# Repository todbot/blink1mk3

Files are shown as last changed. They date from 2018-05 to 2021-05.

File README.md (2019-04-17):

# blink(1) mk3 -- USB RGB LED notification light

This repo lives at https://github.com/todbot/blink1mk3

blink(1) mk3 is a blink(1) USB device: https://blink1.thingm.com

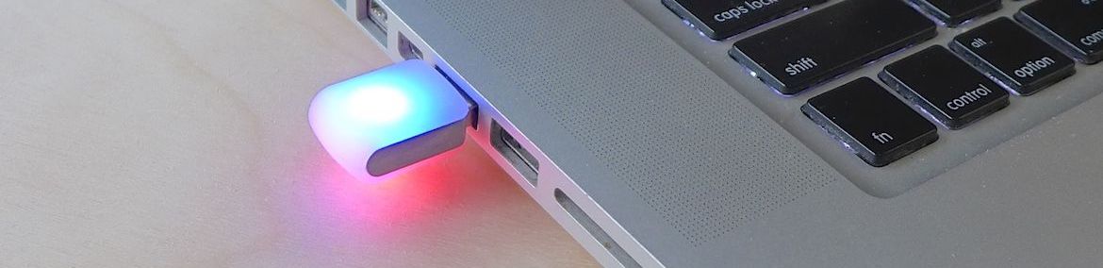
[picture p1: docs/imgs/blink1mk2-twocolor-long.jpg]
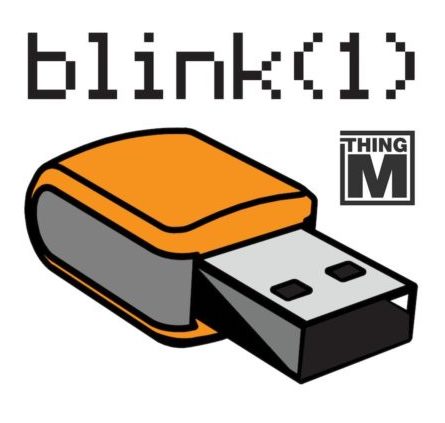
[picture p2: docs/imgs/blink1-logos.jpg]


"[blink(1) mk3](https://blink1.thingm.com/) is an update to blink(1).
blink(1) is a super status light:
it packs three dimensions of information
(color, brightness and pattern) into a single tiny package that fits into
any USB port on nearly every device. It makes it incredibly easy to connect
any data source in the cloud or on your computer to a full-color RGB LED so
you can know what's happening without checking any windows, going to any
websites or typing any commands." - Get a blink(1) at https://buy.thingm.com/

More technically, blink(1) is a Smart LED controller with built-in USB firmware. blink(1) has a huge range of support from the Linux kernel to Node.js.

This repo contains:

- firmware -- blink(1) firmware for blink1mk3 (on DEFM32HG309F64, same as Tomu)
- bootloader -- DFU firmware for blink(1), based on tomu-bootloader
- schematic -- schematic diagrams of blink(1) mk3

The official repositories for blink(1) software are:

| repository | description |
| --- | --- |
| [Blink1Control2](https://github.com/todbot/Blink1Control2) | Graphical app for Mac / Windows / Linux |
| [blink1-tool](https://github.com/todbot/blink1-tool) | Command-line tools & C-library for all platforms |
| [blink1-java](https://github.com/todbot/blink1-java) | Java and Processing library |
| [blink1-python](https://github.com/todbot/blink1-python) | Python library |
| [node-blink1](https://github.com/sandeepmistry/node-blink1) | Node.js library |
| [blink1](https://github.com/todbot/blink1) | Hardware/firmware design for mk1/mk2, misc docs & notes
| [blink1mk3](https://github.com/todbot/blink1mk3) | Hardware/firmware design for mk3

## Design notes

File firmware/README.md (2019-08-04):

# blink1mk3 firmware

## What is this:

This is firmware for the blink(1) mk3 USB RGB LED device.
It borrows heavily from the [Tomu](http://tomu.im) project.
This directory started as a fork of the
[tomu-samples](https://github.com/im-tomu/tomu-samples) repository.

## How to use:

1. To compile these, you'll need a cross-compiling toolchain to arm-none-eabi.

  - Debian/Ubuntu/... : `sudo apt-get install gcc-arm-none-eabi`
  - Fedora : `sudo yum install arm-none-eabi-gcc-cs arm-none-eabi-newlib`
  - Arch : `sudo pacman -S arm-none-eabi-gcc arm-none-eabi-newlib`
  - Other Linux : check your package manager, or
  - Anything else (Windows, OSX, Linux) : [https://developer.arm.com/open-source/gnu-toolchain/gnu-rm ](https://developer.arm.com/open-source/gnu-toolchain/gnu-rm )

  If the cross compiling toolchain is in your PATH then the Makefile will
  auto-detect it; else (or to override it) specify it using the environment
  variable "CROSS_COMPILE".
  There might be additional dependencies, depending on which specific project
  you're using, and the instructions for compilation are included in each
  project's README.md

2. Run `make deps .` to patch the linker with support for the blink(1) and Tomu
    and clone the [Gecko SDK](https://github.com/SiliconLabs/Gecko_SDK) locally

3. Now you can build the firmware.

4. The production firmware is located in `firmware-v30x`.

## Flashing:

The easiest way to upload a new firmware is to trigger the USB DFU bootloader
and use `dfu-util` to upload the new firmware.  For an example of how to do this,
see the "program-dfu" Makefile target in `firmware-v30x` or the "fw-updates" directory.

You can also solder wires to the programming test pads:
"5V" (+5VDC), "G" (gnd), "D" (SWD), "C" (SWC) pins
then use any JTAG/SWD programmer to upload new code.

## Testing:

In Windows, install the app "TDD.exe"
(https://www.thesycon.de/eng/usb_descriptordumper.shtml)
It is very good at detecting subtle errors in USB configuration that MacOS & Linux
point out.

On Mac OS X, install "USB Prober"

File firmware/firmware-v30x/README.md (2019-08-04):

# blink(1) mk3 - firmware-v30x

This is the standard firmware for blink(1) mk3 devices.

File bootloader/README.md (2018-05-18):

# blink(1) mk3 bootloader

This bootloader is equivalent to the Tomu bootloader with a few small changes:
- USB VID/PID different
- Bootloader can ONLY be triggered by either:
  - SWD & SWC pins shorted
  - RAM setting "TOBOOT_FORCE_ENTRY_MAGIC" (via `blink1-tool --gobootload`)

These changes are encapsulated in the files in this directory:
- `usb_desc.h` -- replaces normal `tomu-bootloader/toboot/usb_desc.h`
- `toboot-main-blink1.c` -- replaces normal `tomu-bootloader/toboot/main.c`

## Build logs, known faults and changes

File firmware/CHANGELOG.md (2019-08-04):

# blink(1) mk3 firmware changelog

List of official firmwares for blink(1) mk3:

- v302 -- 2018-2019 production firmware

- v303 -- 2Aug2019 - work-around for USB Suspend causing main thread(and pattern playing) to stop.

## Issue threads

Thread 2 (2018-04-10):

Add option to ensure physical security of bootloader

todbot, 2018-04-10:
As @carlynorama pointed out, blink(1) mk3's reprogrammability could pose security issues for certain users. To address this, create a new feature in the blink(1) API and firmware that disables USB-based triggering of the DFU bootloader.

The process would be:
- New USB command that "locks out" the USB triggering of the bootloader
- Bootloader will then only run when 'S' & 'D' solder pads are physically jumpered, meaning physical access to device, and the device removed from its enclosure
- To re-enable "unlocked" mode, factory firmware must be reloaded onto device

todbot, 2019-04-17:
done.

Closed 2019-04-17.

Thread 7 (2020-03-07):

Firmware Update not running

lucaobermaier, 2020-03-07:
Firmware Update is not running correctly:

Last login: Sat Mar  7 18:49:14 on ttys000
lucaobermaier@Lucas-MBP ~ % /Users/lucaobermaier/Downloads/blink1mk3-master/blink1mk3_fw_update/blink1mk3-update-macos.command ; exit;
------
Putting blink(1) into bootloader mode
Changing blink(1) mk3 to bootloader...
Use dfu-util to upload new firmare
Or replug device to go back to normal
blink1 response: 'GOBOOT'
blink(1) in bootloader mode
------
Waiting for bootloader USB reconnect...
c------
Programming new firmware
dyld: Library not loaded: /usr/local/opt/libusb/lib/libusb-1.0.0.dylib
  Referenced from: /Users/lucaobermaier/Downloads/blink1mk3-master/blink1mk3_fw_update/./tools/dfu-util
  Reason: image not found
/Users/lucaobermaier/Downloads/blink1mk3-master/blink1mk3_fw_update/blink1mk3-update-macos.command: line 14: 88017 Abort trap: 6           ./tools/dfu-util -v --device 27B8:01ED --download *dfu
------
Done!

todbot, 2020-03-07:
Hi,
Do you use Homebrew (https://brew.sh/)?  That error is because the `dfu-util` tool can't find the libusb library. (I tried to make static versions of that tool but clearly did not)

If you use Homebrew, you can do `brew install libusb` and try rerunning the update command.

If you don't use Homebrew, I'm looking into getting a statically-compiled version of `dfu-util`.

Thanks for being patient.

lucaobermaier, 2020-03-07:
Hey,

Thanks for the quick reply.
No I am not using home-brew.
I also get the error on the windows machine: " Could not open file *dfu for reading.“
Is that the same thing?
Best regards

Luca Obermaier
Event Technology Specialist

Obermaier Event Support
Nachtigallenweg 13
65719 Hofheim am Taunus
Phone: +49 (0) 6192/2069694
Mobile: +49 (0) 151/27003039
Fax: +49 (0) 3222/4284647
E-mail: mail@lucaobermaier.de
Website:: www.lucaobermaier.de

Die AGB finden Sie auf der oben genannten Webpräsenz.

Vertraulichkeitshinweis:
Diese Nachricht ist ausschließlich für die Personen bestimmt, an die sie adressiert ist. Sie kann vertrauliche und/oder nur für den/die Empfänger bestimmte Informationen enthalten. Sollten Sie nicht der bestimmungsgemäße Empfänger sein, kontaktieren Sie bitte den Absender und löschen Sie die Mitteilung. Jegliche unbefugte Verwendung der Informationen in dieser Nachricht ist untersagt.

Confidentiality Note:
This message is intended only for the use of the named recipient(s) and may contain confidential and/or privileged information. If you are not the intended recipient, please contact the sender and delete the message. Any unauthorized use of the information contained in this message is prohibited.

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

todbot, 2020-03-07:
Are you running the Windows .bat file from a CMD window or Powershell?  It is only for a CMD window.

Apologies these aren't scripts aren't tested much.  There's only been one official firmware update for blink(1) mk3 (some early units had v302, most all current ones have v303)   You can find your blink(1)'s version by doing `blink1-tool --version`.

It's likely you do not need to update the firmware on your blink(1) anyway.

I have updated https://github.com/todbot/blink1mk3/releases with "blink1mk3_fw_update_fw303-2Aug2019b.zip", containing an updated `dfu-util` for Mac. If you still want to give it a try, I think that one will work.

lucaobermaier, 2020-03-07:
I was using CMD not powershelgl.

I have some 302 early units and problems with the blink1 control center. My hope was that the firmware update will fix those crashes.
Just downloaded the new release.

Last login: Sat Mar  7 20:00:35 on ttys000
/Users/lucaobermaier/Downloads/blink1mk3_fw_update/blink1mk3-update-macos.command ; exit;
lucaobermaier@Lucas-MBP ~ % /Users/lucaobermaier/Downloads/blink1mk3_fw_update/blink1mk3-update-macos.command ; exit;
------
Putting blink(1) into bootloader mode
Changing blink(1) mk3 to bootloader...
Use dfu-util to upload new firmare
Or replug device to go back to normal
blink1 response: 'GOBOOT'
blink(1) in bootloader mode
------
Waiting for bootloader USB reconnect...
------
Programming new firmware
dfu-util 0.9

Copyright 2005-2009 Weston Schmidt, Harald Welte and OpenMoko Inc.
Copyright 2010-2016 Tormod Volden and Stefan Schmidt
This program is Free Software and has ABSOLUTELY NO WARRANTY
Please report bugs to http://sourceforge.net/p/dfu-util/tickets/

DFU suffix version 100
Opening DFU capable USB device...
ID 27b8:01ee
Run-time device DFU version 0101
Claiming USB DFU Interface...
Setting Alternate Setting #0 ...
dfu-util: Cannot set alternate interface
------
Done!

[Prozess beendet]

Stil on 302.

Best regards

Luca Obermaier
Event Technology Specialist

Obermaier Event Support
Nachtigallenweg 13
65719 Hofheim am Taunus
Phone: +49 (0) 6192/2069694
Mobile: +49 (0) 151/27003039
Fax: +49 (0) 3222/4284647
E-mail: mail@lucaobermaier.de
Website:: www.lucaobermaier.de

Die AGB finden Sie auf der oben genannten Webpräsenz.

Vertraulichkeitshinweis:
Diese Nachricht ist ausschließlich für die Personen bestimmt, an die sie adressiert ist. Sie kann vertrauliche und/oder nur für den/die Empfänger bestimmte Informationen enthalten. Sollten Sie nicht der bestimmungsgemäße Empfänger sein, kontaktieren Sie bitte den Absender und löschen Sie die Mitteilung. Jegliche unbefugte Verwendung der Informationen in dieser Nachricht ist untersagt.

Confidentiality Note:
This message is intended only for the use of the named recipient(s) and may contain confidential and/or privileged information. If you are not the intended recipient, please contact the sender and delete the message. Any unauthorized use of the information contained in this message is prohibited.

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

todbot, 2020-03-07:
Hi,
This is probably a Mac Catalina issue.  Many tools like these have had issues since Catalina.  .I'm also seeing this now and dfu-util worked before I upgraded.

Please describe in more detail these crashes you've been having. If Blink1Control2 is crashing on you, updating the firmware on the blink(1) will not help.   Please open up an issue describing the what you're seeing at: https://github.com/todbot/blink1control2/issues

The firmware update only addresses use cases where you're using the `blink1-tool --play` internal pattern player, which Blink1Control2 does not use. I'll continue investigating what is wrong with Mac dfu-util but I think we should address the crashes first.

Thanks

lucaobermaier, 2020-03-07:
I tried your install with windows now.
There it work perfectly.
Thats solved 😉

Luca Obermaier
Event Technology Specialist

Obermaier Event Support
Nachtigallenweg 13
65719 Hofheim am Taunus
Phone: +49 (0) 6192/2069694
Mobile: +49 (0) 151/27003039
Fax: +49 (0) 3222/4284647
E-mail: mail@lucaobermaier.de
Website:: www.lucaobermaier.de

Die AGB finden Sie auf der oben genannten Webpräsenz.

Vertraulichkeitshinweis:
Diese Nachricht ist ausschließlich für die Personen bestimmt, an die sie adressiert ist. Sie kann vertrauliche und/oder nur für den/die Empfänger bestimmte Informationen enthalten. Sollten Sie nicht der bestimmungsgemäße Empfänger sein, kontaktieren Sie bitte den Absender und löschen Sie die Mitteilung. Jegliche unbefugte Verwendung der Informationen in dieser Nachricht ist untersagt.

Confidentiality Note:
This message is intended only for the use of the named recipient(s) and may contain confidential and/or privileged information. If you are not the intended recipient, please contact the sender and delete the message. Any unauthorized use of the information contained in this message is prohibited.

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

todbot, 2020-03-07:
That's good.  I've also found the issue with `dfu-util` on MacOS and updated the zip yet again.

So I'll close this issue. But if you have crashes in Blink1Control2, please open up an issue there.

Thanks for being a customer and thanks for pointing out this problem with the update script.

lucaobermaier, 2020-03-07:
I will do. Blink1control is a different thing 😉
Thanks for taking care so fast. 👏🏽

Best regards

Von meinem iPhone gesendet

Luca Obermaier
Fachkraft für Veranstaltungstechnik

Obermaier Event Support
Nachtigallenweg 13
65719 Hofheim am Taunus
Phone: +49 (0) 6192/2069694
Mobile: +49 (0) 151/27003039
Fax: +49 (0) 3222/4284647
E-mail: mail@lucaobermaier.de
Website:: www.lucaobermaier.de

Die AGB finden Sie auf der oben genannten Webpräsenz.

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

Closed 2020-03-07.

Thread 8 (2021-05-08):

blink1-tool --setstartup doesn't quite work

ChrMa, 2021-05-08:
Hi,

I noticed, that when I use `--setstartup` to keep the blink1mk3 from running it's sequence when power is applied (mode 2), it won't let me start playing the programmed sequence using `blink1-tool --play` either. It seems to me that there is a bug in firmware/firmware-v30x/main.c, line 708, where `doStartup` is set every time after the first second of runtime.

Another problem I encountered is, that when I program the blink1mk3 to play just part of it's sequence or just a few repetitions on power up, e.g. using `blink1-tool --setstartup 0,0,5,10`, it nevertheless plays the full sequence without ever stopping.
```
$ blink1-tool --setstartup 0,0,5,10
set startup params: bootmode: 0, play start/end/count: 0/5/10
$ /bin/blink1-tool --getstartup
get startup params: bootmode: 0, play start/end/count: 0/5/10
```
When connecting it to a power bank afterwards, the full sequence plays. When using bootmode 1, it even says so when reading back the playstate:
```
$ blink1-tool --setstartup 1,0,5,10
set startup params: bootmode: 1, play start/end/count: 0/5/10
$ blink1-tool --getstartup
get startup params: bootmode: 1, play start/end/count: 0/5/10
$ # unplug an reinsert blink1 device
$ blink1-tool --getstartup
get startup params: bootmode: 1, play start/end/count: 0/5/10
$ blink1-tool --playstate
playstate: playing:1 start-end:0-31 count:0 pos:6
```
I wasn't able to spot any suspicious line of code, that would explain this phenomenon however.

ChrMa, 2021-05-08:
Sorry, forgot to add version information.
```
$ blink1-tool --version
blink1-tool version: v2.1.0-linux-x86_64, fw version: 303
$ blink1-tool --fwversion
id:0 - firmware:303 serialnum:********
```

todbot, 2021-05-08:
Hi @ChrMa,

For the first issue (`--play` not working as expected), how are you invoking it?  You need to say:
```
blink1-tool --play 1
```
to start the pattern playing and
```
blink1-tool --play 0
```
to stop.  Or `blink1-tool --stop`.  (This is support upstream callers of `blink1-tool` that expects to be able to pass an argument for play/stop).  Apologies that isn't documented well.

As to the second issue you mention about the startup parameters not being heeded, I am looking into that now.

ChrMa, 2021-05-08:
To recreate the first issue, I start off with resetting the device to defaults:
```
$ blink1-tool --setstartup 0,0,31,0
set startup params: bootmode: 0, play start/end/count: 0/31/0
```
Now i disconnect and reconnect the device. It briefly flashes white, then stays off.
```
$ blink1-tool --getstartup
get startup params: bootmode: 0, play start/end/count: 0/31/0
$ blink1-tool --playstate
playstate: playing:0 start-end:0-31 count:0 pos:0
```
Now I switch to mode 1:
```
$ blink1-tool --setstartup 1,0,31,0
set startup params: bootmode: 1, play start/end/count: 0/31/0
```
The device immediately plays the preprogrammed color sequence. I disconnect and reconnect it again and shortly after the white flash it starts playing the pattern. Now I try to stop it:
```
$ blink1-tool --play 0
stopping color pattern from pos 0-0 (0 times)
```
However it doesn't stop, it just jumps back to the beginning of the programmed pattern and continues playing it from there. Trying to stop it multiple times also doen't help, it always just jumps back to the beginning of the sequence.

Now lets switch to mode 2:
```
$ blink1-tool --setstartup 2,0,31,0
set startup params: bootmode: 2, play start/end/count: 0/31/0
```
Immediately, the device stops playing the pattern. I disconnect and reconnect it to the computer. It briefly flashes white and then stays dark. Now I try to start the pattern again:
```
$ blink1-tool --play 1
playing color pattern from pos 0-0 (0 times)
```
For a split second one of the LEDs start ramping up the red light, then the sequence stops and the red light is on continuously.
If I call `blink1-tool --play 1` again, nothing visible happens, one LED stays  red, the other one stays dark.
By the way: ramping up one LED in red is the first step of the preprogrammed pattern sequence:
```
$ blink1-tool --getpattline 0
reading rgb at pos  0: r,g,b = 0xff,0x00,0x00 (1) ms:500
```
Hope that helps.

todbot, 2021-05-08:
Thanks for the detailed description. It's very helpful. I am investigating now. I will admit the built-in color pattern code is not as well exercised as it used by many fewer people. It should still work though.

todbot, 2021-05-08:
Hi, I just published an attempted fix for the issue you describe. You can install it using a Chrome-based browser as described here: https://github.com/todbot/blink1mk3/releases/tag/firmware-v304

Let me know if it works for you. I'm still testing but I wanted to provide a testable solution for you as quickly as possible.

Thank you for submitting this issue! I've been wanting to revisit the blink(1) mk3 firmware.

ChrMa, 2021-05-09:
Thanks for the fix. The issues I described in my last message are completely resolved. I can now start and stop the playing of patterns as expected, no matter what bootmode the blink1 device started with. Also changing the bootmode with `--setstartup` no longer has any immediate effect on the playstatus. For my use case, this is good enough.

However the problem where the play start/end/count parts of the '--setstartup' parameters are ignored still persists and I haven't got the slightest clue as to what is causing this. For context: my device still has the original blink pattern programmed in, so
```
$ blink1-tool --play 1,3,5,2
playing color pattern from pos 3-5 (2 times)
```
ramps up both leds in green, one after the other, and then ramps both down to black simultaneously. After two cycles, it stops playing.
However when I do
```
$ blink1-tool --setstartup 1,3,5,2
set startup params: bootmode: 1, play start/end/count: 3/5/2
```
And then disconnect and reconnect the device, it starts playing the whole programmed sequence forever
```
$ blink1-tool --playstate
playstate: playing:1 start-end:0-31 count:0 pos:11
$ blink1-tool --getstartup
get startup params: bootmode: 1, play start/end/count: 3/5/2
```

ChrMa, 2021-05-09:
I think I just found the problem: The gcc compiler is just too intelligent for its own good.
In firmware/firmware-v30x/main.c, lines 868-879, you first copy the content of userFlash into userData and then copy the play start/end/count values from userData to the individual variables. At this point gcc seems to understand, that userData must contain the same as userFlash and that userFlash is constant and has to contain the values specified in lines 243-250, so it already knows what goes into the playstart, playend and playcount variables and doesn't bother to load it from either userData or userFlash.
So the line
```
playend   = userData.startup_params.playend;
```
becomes
```
movs    r2, #32
ldr     r3, [pc, #736]
strb    r2, [r3, #0]
```
My suggestion would be to remove the `const` qualifier from userFlash in line 240, which results in the above line to become
```
ldr     r7, [pc, #748]
ldrb    r2, [r7, #2]
ldr     r3, [pc, #740]
strb    r2, [r3, #0]
```
Unfortunately, since I don't have any debugger or even a means to recover from flashing broken software, I have not tested this change on real hardware.

todbot, 2021-05-09:
Hi!  Thanks again for the detailed look into this issue.  I've uploaded an updated firmware DFU for you to try on the Releases page called `blink1mk3-v304a-20210509.dfu`.  Please let me know if it solves the `setplaystate` issue for you. It does for me, but if you look at the change, I'm sure you'll be thinking "WTF?".

With these chips and its attendant SDK, there's a few different issues when dealing with flash memory for data storage. The most noticeable is that variables must be 32-bit aligned. This might actually be what's happening as the code works as intended when DEBUG is enabled (which adds a few buffers for the UART). My change adds a 100ms delay. It's a hack but might also be addressing the vague memory I have of the older EFM32 SDK I'm using not properly on flash reads.

ChrMa, 2021-05-09:
Thanks for the new firmware. I tested it and it worked flawlessly.

 I'm not sure I agree, that the extra 100ms delay made the difference. I think it's more likely the fact, that there is now a function call after `userDataLoad()`, which forces gcc to consider the data in userData to be possibly changed. You might want to compare the debug information in blink1mk3.dump before and after the fix for details.

Then again the firmware works now as expected, so I am satisfied. Thanks again for the support.

mhalano, 2022-07-23:
@ChrMa Can this issue be closed for good?

@todbot There is a reason why not release the 304 firmware to public use?

todbot, 2022-07-23:
Hi @mhalano,

Thanks! I had forgotten that v304 was labeled as pre-release and not normal release.
Just changed that now and will close this comment.

And thanks @ChrMa for raising this issue and testing!

mhalano, 2022-07-23:
@todbot Just a remaining question: what is the correct file? I checked and they have different checksums.
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

todbot, 2022-07-23:
Thanks. I've eliminated the older one.  (Everything was was a bit hectic a year ago)

Closed 2022-07-23.

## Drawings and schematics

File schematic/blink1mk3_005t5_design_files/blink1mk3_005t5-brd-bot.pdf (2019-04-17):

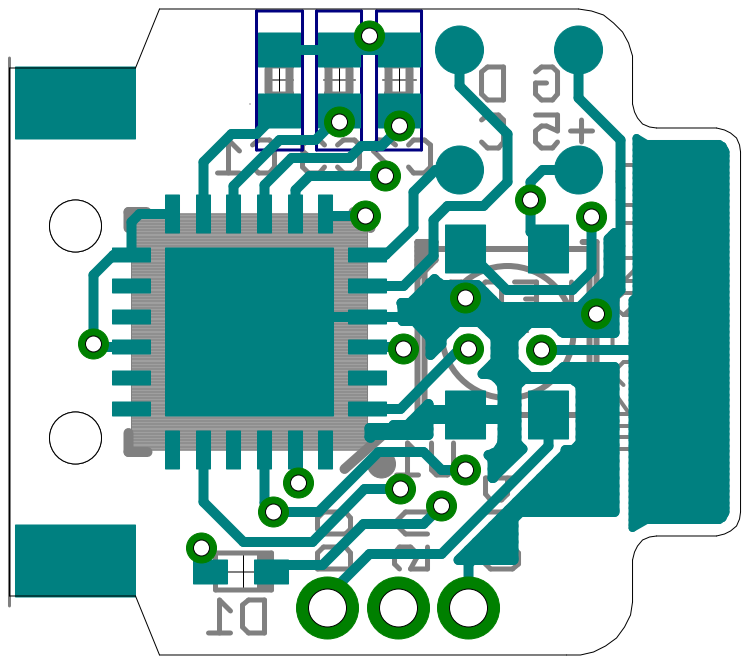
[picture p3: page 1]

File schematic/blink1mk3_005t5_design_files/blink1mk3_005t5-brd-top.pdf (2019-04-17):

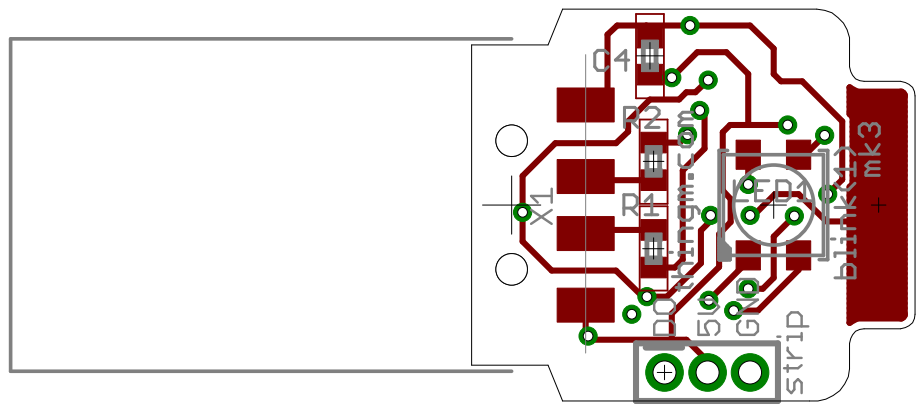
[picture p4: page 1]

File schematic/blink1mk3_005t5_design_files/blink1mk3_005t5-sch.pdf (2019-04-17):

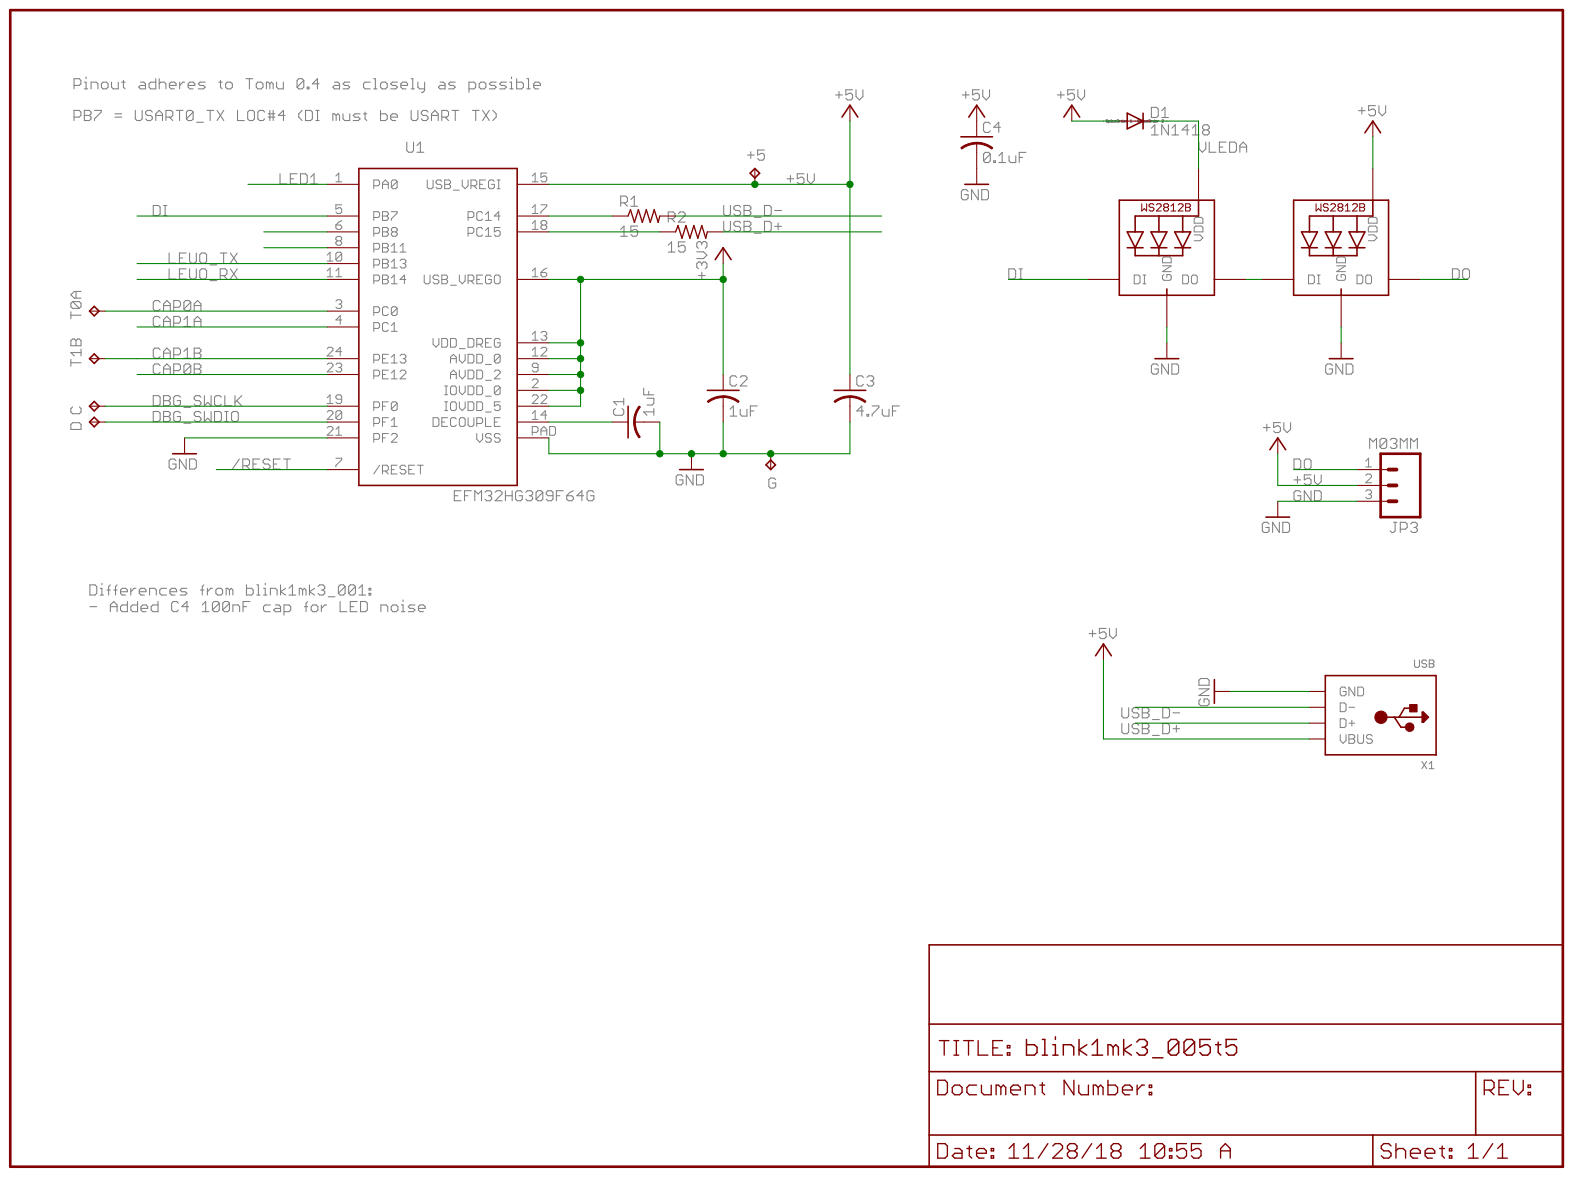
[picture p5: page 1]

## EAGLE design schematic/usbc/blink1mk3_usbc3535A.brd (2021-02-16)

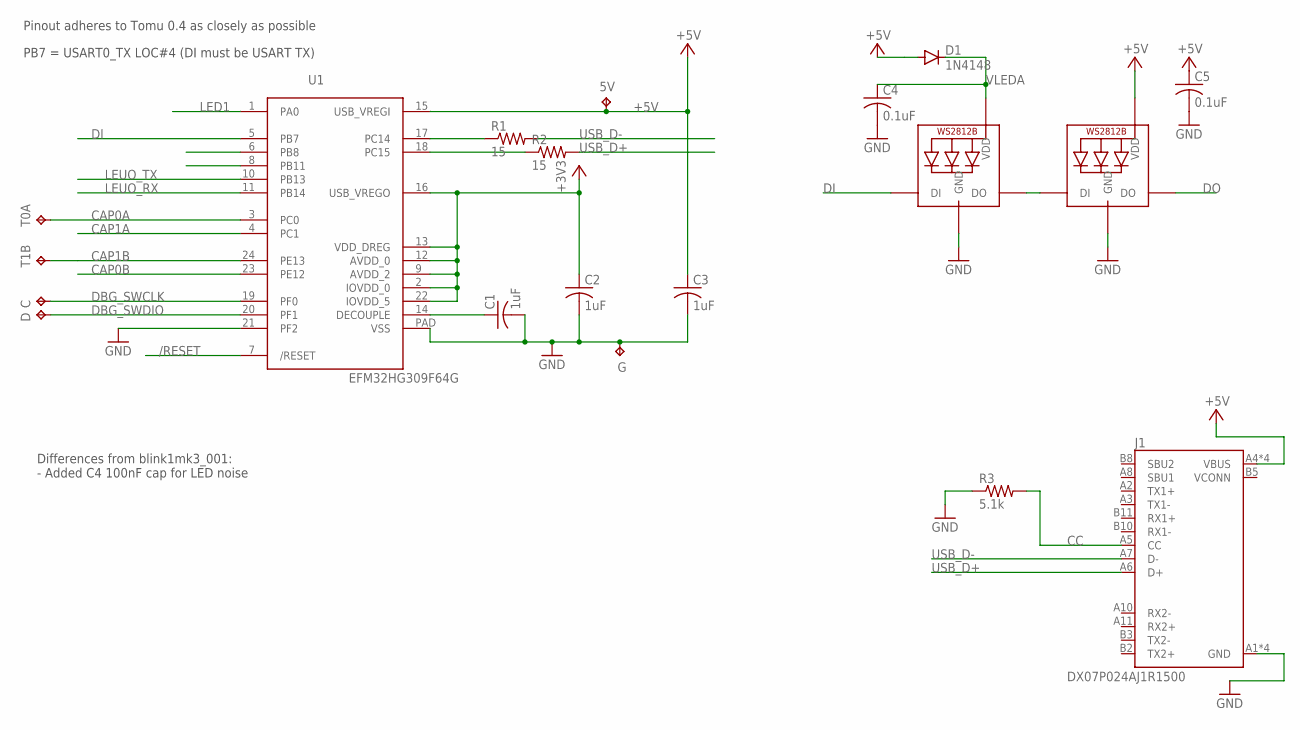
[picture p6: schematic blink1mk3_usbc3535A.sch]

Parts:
5V: TPTP10R; TP10R
C: TPTP10R; TP10R
C1, C2, C3: 1uF; C0402
C4, C5: 0.1uF; C0402
D: TPTP10R; TP10R
D1: 1N4148; SOD523
G: TPTP10R; TP10R
J1: DX07P024AJ1R1500; JAE_DX07P024AJ1R1500
LED1: WS2812B3535; LED3535
LED2: SK6812MINI; LED3535
R1, R2: 15; R0402
R3: 5.1k; R0402
T0A, T1B: TPTP10R; TP10R
U1: EFM32HG309F64G; QFN24PAD

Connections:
+3V3: C2.1, U1.2 (IOVDD_0), U1.9 (AVDD_2), U1.12 (AVDD_0), U1.13 (VDD_DREG), U1.16 (USB_VREGO), U1.22 (IOVDD_5)
+5V: 5V.TP, C3.1, C5.1, D1.A, J1.A4 (VBUS), J1.A9 (VBUS), J1.B4 (VBUS), J1.B9 (VBUS), LED2.2 (VDD), U1.15 (USB_VREGI)
/RESET: U1.7 (/RESET)
CAP0A: T0A.TP, U1.3 (PC0)
CAP0B: U1.23 (PE12)
CAP1A: U1.4 (PC1)
CAP1B: T1B.TP, U1.24 (PE13)
CC: J1.A5 (CC), R3.2
DBG_SWCLK: C.TP, U1.19 (PF0)
DBG_SWDIO: D.TP, U1.20 (PF1)
DECOUPLE: C1.1, U1.14 (DECOUPLE)
DI: LED1.1 (DI), U1.5 (PB7)
DO: LED2.3 (DO)
GND: C1.2, C2.2, C3.2, C4.2, C5.2, G.TP, J1.A1 (GND), J1.A12 (GND), J1.B1 (GND), J1.B12 (GND), LED1.4 (GND), LED2.4 (GND), R3.1, U1.21 (PF2), U1.PAD (VSS)
LED1: U1.1 (PA0)
LEUO_RX: U1.11 (PB14)
LEUO_TX: U1.10 (PB13)
unnamed: LED1.3 (DO), LED2.1 (DI)
RUSB_D+: R2.1, U1.18 (PC15)
RUSB_D-: R1.1, U1.17 (PC14)
USB_D+: J1.A6 (D+), R2.2
USB_D-: J1.A7 (D-), R1.2
VCONN: J1.B5 (VCONN)
VLEDA: C4.1, D1.C, LED1.2 (VDD)

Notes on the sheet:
PB7 = USART0_TX LOC#4 (DI must be USART TX)
Pinout adheres to Tomu 0.4 as closely as possible
Differences from blink1mk3_001: - Added C4 100nF cap for LED noise

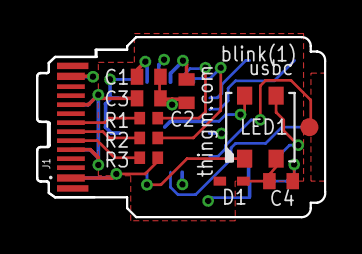
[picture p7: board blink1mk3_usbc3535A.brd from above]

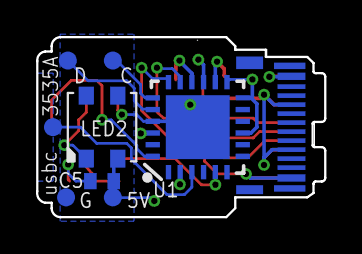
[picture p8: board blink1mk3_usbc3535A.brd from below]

Board: 4 copper layers, 16.0 x 10.0 mm, 19 parts (8 on the bottom side), 16 nets.

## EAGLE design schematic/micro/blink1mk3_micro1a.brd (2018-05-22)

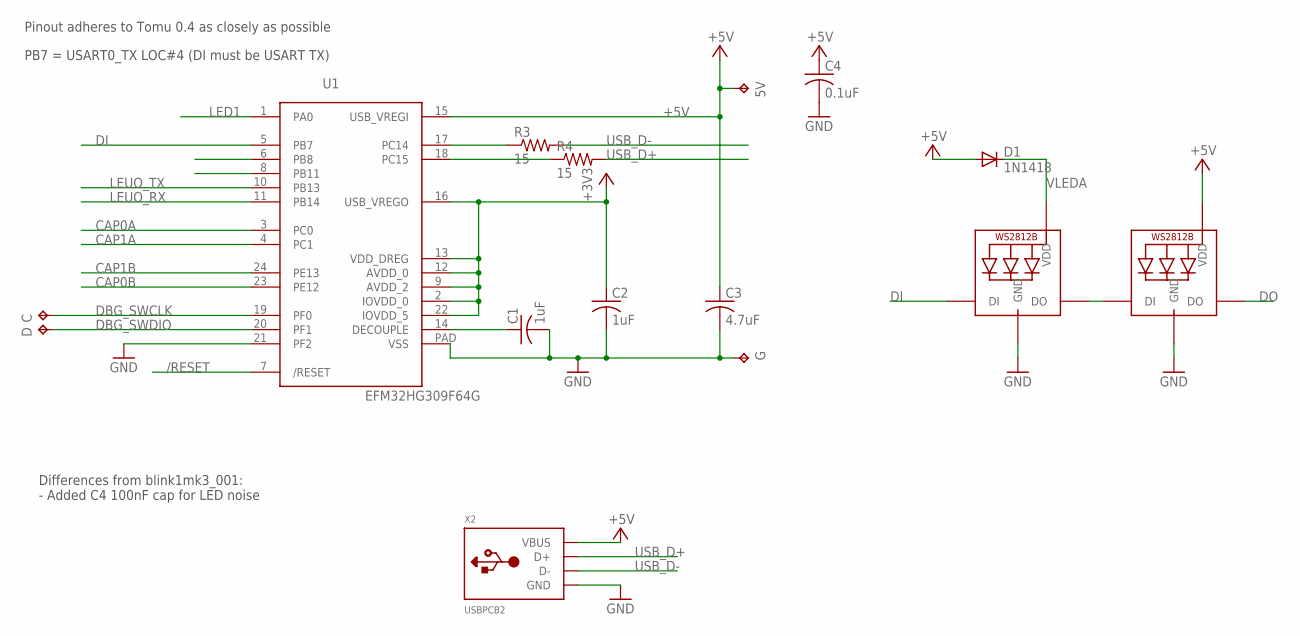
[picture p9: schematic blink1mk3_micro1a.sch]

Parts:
5V: TPTP10R; TP10R
C: TPTP10R; TP10R
C1, C2: 1uF; C0402
C3: 4.7uF; C0402
C4: 0.1uF; C0402
D: TPTP10R; TP10R
D1: 1N1418; SOD523
G: TPTP10SQ; TP10SQ
LED1, LED2: WS2812B4020SIDE; SK6812-SIDE
R3, R4: 15; R0402
U1: EFM32HG309F64G; QFN24PAD
X2: USBPCB2; USB-A-PCB-2

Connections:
+3V3: C2.1, U1.2 (IOVDD_0), U1.9 (AVDD_2), U1.12 (AVDD_0), U1.13 (VDD_DREG), U1.16 (USB_VREGO), U1.22 (IOVDD_5)
+5V: 5V.TP, C3.1, C4.1, D1.A, LED2.1-VDD (VDD), U1.15 (USB_VREGI), X2.5V (VBUS)
/RESET: U1.7 (/RESET)
CAP0A: U1.3 (PC0)
CAP0B: U1.23 (PE12)
CAP1A: U1.4 (PC1)
CAP1B: U1.24 (PE13)
DBG_SWCLK: C.TP, U1.19 (PF0)
DBG_SWDIO: D.TP, U1.20 (PF1)
DECOUPLE: C1.1, U1.14 (DECOUPLE)
DI: LED1.4-DIN (DI), U1.5 (PB7)
DO: LED2.2-DOUT (DO)
GND: C1.2, C2.2, C3.2, C4.2, G.TP, LED1.3-GND (GND), LED2.3-GND (GND), U1.21 (PF2), U1.PAD (VSS), X2.GND
LED1: U1.1 (PA0)
LEUO_RX: U1.11 (PB14)
LEUO_TX: U1.10 (PB13)
unnamed: LED1.2-DOUT (DO), LED2.4-DIN (DI)
RUSB_D+: R4.1, U1.18 (PC15)
RUSB_D-: R3.1, U1.17 (PC14)
USB_D+: R4.2, X2.USB_P (D+)
USB_D-: R3.2, X2.USB_M (D-)
VLEDA: D1.C, LED1.1-VDD (VDD)

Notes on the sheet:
PB7 = USART0_TX LOC#4 (DI must be USART TX)
Pinout adheres to Tomu 0.4 as closely as possible
Differences from blink1mk3_001: - Added C4 100nF cap for LED noise

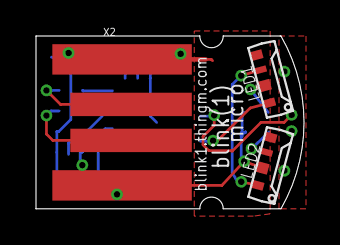
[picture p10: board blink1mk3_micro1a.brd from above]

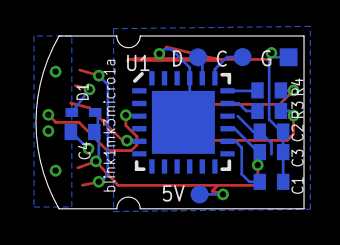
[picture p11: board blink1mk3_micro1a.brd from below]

Board: 2 copper layers, 14.9 x 9.6 mm, 15 parts (12 on the bottom side), 13 nets.

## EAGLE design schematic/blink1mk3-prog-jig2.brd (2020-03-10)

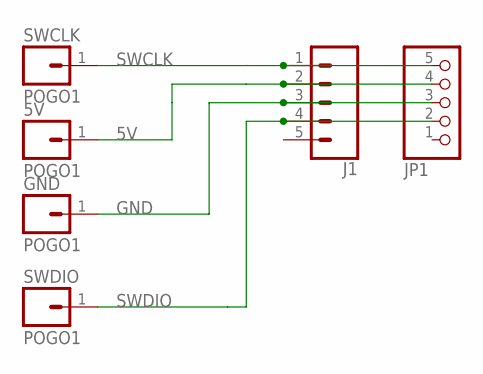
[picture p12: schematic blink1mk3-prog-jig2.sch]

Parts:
5V: POGO1; MILLMAX-0928-POGO-THRU
GND: POGO1; MILLMAX-0928-POGO-THRU
J1: CONN_05; 1X05
JP1: PINHD-1X5/90; 1X05/90
SWCLK: POGO1; MILLMAX-0928-POGO-THRU
SWDIO: POGO1; MILLMAX-0928-POGO-THRU

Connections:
5V: 5V.1, J1.2, JP1.4
GND: GND.1, J1.3, JP1.3
SWCLK: J1.1, JP1.5, SWCLK.1
SWDIO: J1.4, JP1.2, SWDIO.1

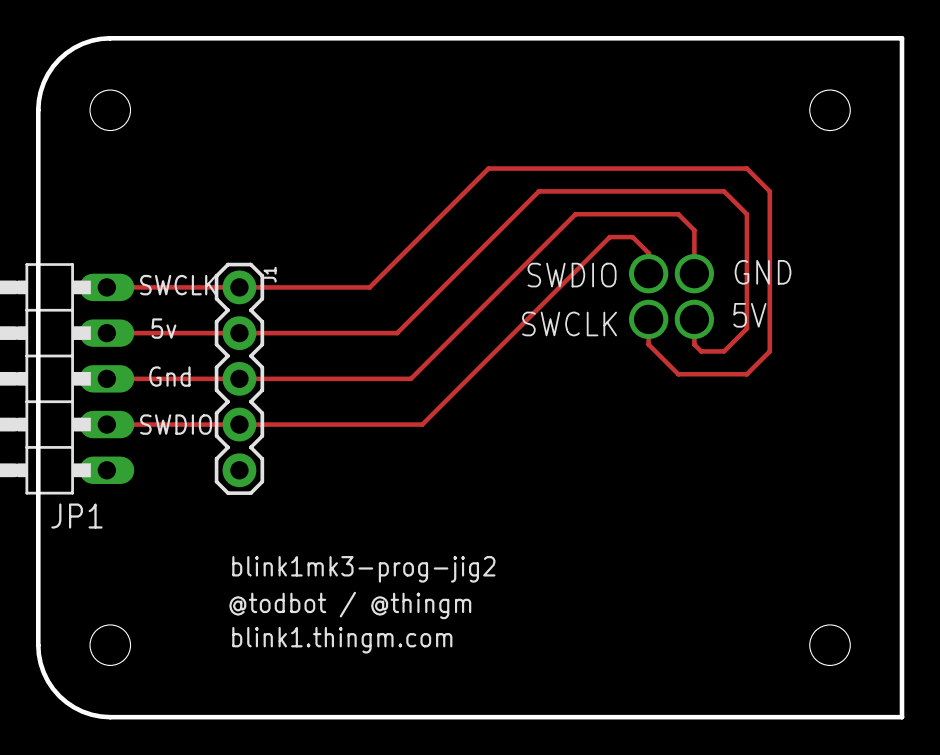
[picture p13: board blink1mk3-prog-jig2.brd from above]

Board: 2 copper layers, 48.0 x 37.7 mm, 6 parts (0 on the bottom side), 4 nets.

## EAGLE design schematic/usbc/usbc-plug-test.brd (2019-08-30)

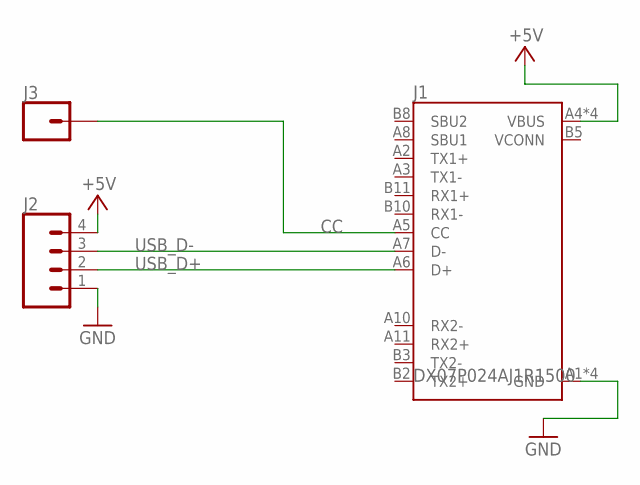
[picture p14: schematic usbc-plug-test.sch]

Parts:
J1: DX07P024AJ1R1500; JAE_DX07P024AJ1R1500
J2: CONN_04; 1X04
J3: CONN_01; 1X01

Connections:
+5V: J1.A4 (VBUS), J1.A9 (VBUS), J1.B4 (VBUS), J1.B9 (VBUS), J2.4
CC: J1.A5 (CC), J3.1
GND: J1.A1 (GND), J1.A12 (GND), J1.B1 (GND), J1.B12 (GND), J2.1
USB_D+: J1.A6 (D+), J2.2
USB_D-: J1.A7 (D-), J2.3
VCONN: J1.B5 (VCONN)

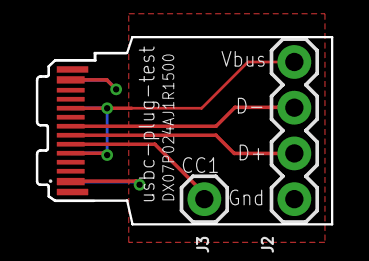
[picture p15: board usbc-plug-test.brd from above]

Board: 2 copper layers, 16.4 x 10.4 mm, 3 parts (0 on the bottom side), 5 nets.

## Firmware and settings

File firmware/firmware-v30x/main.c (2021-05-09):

/*********************************************************************************************
 *
 * blink1mk3 firmware -- EFM32HG-based blink(1)
 *
 * 2018 Tod E. Kurt, http://todbot.com/blog/
 *  Initially based off work by Tomu project (github.com/im-tomu)
 *
 * For production:
 *  - Disable all DEBUG_ defines
 *  - Check blink1_version_ defines
 *  - Check USB version strings in "descriptors.h"
 *  - Verify latest bootloader is installed
 *
 * Production firmware:
 * - v302 is first production firmware
 *
 * Differences from blink1mk3-test5:
 * - bootloader lockout command implemented
 * - fixed serverdown (aka "servetickle") logic
 * - added serverdown boot settings
 * - changed rgb_t to be r,g,b ordering instead of g,r,b
 *
 * Differences from blink1mk3-test4:
 * - Implements serverdown logic
 * - Uses PLAY_ enum
 *
 * Differences from blink1mk3-test3:
 * - fixed two-report HID descriptor to work on Windows (and you know, be actually correct)
 * - fix usernotes to correctly save to flash
 * - fixes issue with usernotes killing pattern lines
 * - add startup_params
 * - cleaned up debug printing, increased dbgstr size from 30 to 50 bytes
 *
 * Differences from blink1mk3-test1:
 * - responds correctly to ReportId 2 (64-bytes), testable with "blink1-tool -i 2 --testtest"
 * - code reformatted heavily to pull ws2812 driver and color_funcs into separate files
 * - code works on Tomu-class boards
 *
 *
 ********************************************************************************************/

/*
 * Flash Memory Layout
 * -------------
 * 0x0000 \
 * ...     |- DFU bootlaoder (16 kB)
 * 0x3FFF /
 * 0x4000 \
 * ..      -- blink1 program code (46 kB == 64kB - 1kB - 1kB - 16kB)
 * 0xF7FF /
 * 0xF800 \
 * ...     -- User-specified text notes (1 kB)
 * 0xFBFF /
 * 0xFC00 \
 * ...     -- User-specified color patterns (1 kB)
 * 0xFFFF /
 *
 * See "blink1mk3.ld" for details
 */

/*
 * EFM32HG309 Pin Allocation
 * --------------------
 *  1 - PA0        - n/c (LED1 on Tomu)
 *  2 - IOVDD_0    - VCC 3v3
 *  3 - PC0        - ...
 *  4 - PC1        - ...
 *  5 - PB7        - Data In to WS2812-style LEDs (LED0 on Tomu)
 *  6 - PB8        - n/c
 *  7 - /RESET     - n/c
 * 10 - PB13       - n/c (LEUART TX)
 * 11 - PB14       - n/c (LEUART RX)
 * 12 - AVDD_0     - VCC 3v3
 * 13 - AVDD_2     - VCC 3v3
 * 14 - DECOUPLE   - decouple cap
 * 15 - USB VREGI  - USB +5V
 * 16 - USB_VREGO  - VCC 3v3
 * 17 - PC14       - USB D-
 * 18 - PC15       - USB D+
 * 19 - PF0        - SWDCLK
 * 20 - PF1        - SWDIO
 * 21 - PF2        - n/c
 * 23 - PE12       - ...
 * 24 - PE13       - ...
 * 25 - VSS        - Gnd
 *
 */

#include "capsense.h"
#include "usbconfig.h"

#include <em_core.h>
#include <em_msc.h>
#include <em_usart.h>
#include <em_leuart.h>
#include <em_chip.h>
#include <em_cmu.h>
#include <em_device.h>
#include <em_emu.h>
#include <em_gpio.h>
#include <em_usb.h>
#include <em_wdog.h>
#include <em_system.h>

#include <stdint.h>
#include <stdlib.h> // rand()
#include <stdbool.h>

#define blink1_version_major '3'
#define blink1_version_minor '4'

#define DEBUG 0    // enable debug messages output via LEUART, see 'debug.h'
#define DEBUG_STARTUP 0
// define this to print out cmd+args in handleMessage()
#define DEBUG_HANDLEMESSAGE 0

#define BOARD_TYPE BOARD_TYPE_BLINK1MK3       // ws2812 data out on B7
//#define BOARD_TYPE BOARD_TYPE_TOMU          // ws2812 data out on E13
//#define BOARD_TYPE BOARD_TYPE_EFM32HGDEVKIT // ws2812 data out on E10

#define nLEDs 18   // number of LEDS

#include "utils.h"
#include "leuart.h"
#include "debug.h"

#include "toboot.h"
#include "tinyprintf.h"
#include "ws2812_spi.h"
#include "descriptors.h"
#include "color_types.h"


// forward decls
void setLED(uint8_t r, uint8_t g, uint8_t b, uint8_t n);
static inline void displayLEDs(void);
static void off();
#define setLEDsAll(r,g,b) { setLED(r,g,b, 255); } // 255 means all


// allocate faders, one per LED
rgbfader_t fader[nLEDs];

#include "color_funcs.h"   // needs setLED(), nLEDs, fader[] defined


extern struct toboot_runtime toboot_runtime;
/* Declare support for Toboot V2 */
/* To enable your code to run when you first plug in Tomu, pass
 * TOBOOT_CONFIG_FLAG_AUTORUN to this macro.  Otherwise, leave the
 * configuration value at 0 to use the defaults.
 */
TOBOOT_CONFIGURATION(0);
//TOBOOT_CONFIGURATION( TOBOOT_CONFIG_FLAG_AUTORUN );
//
// Note: Must also set "toboot_runtime.boot_count = 0"
// to prevent bootloader from running after 3 power-cycles
// Because apparently the RAM gets enough power to stay alive?x


// valid values for 'bootmode' in startup_param
enum {
    BOOT_NORMAL = 0,  // normal <v205 behavior
    BOOT_PLAY   = 1,  // play a script on startup (servertickle)
    BOOT_OFF    = 2,  // turn off on startup, even with no USB
    BOOT_SERVERDOWN=3, // serverdown mode?  //just an idea, not implemented
};
    
// layout of the startup params bundle
// (v206+ stored a smaller startup params in last patternline)
typedef struct {
  uint8_t bootmode;  // ledn, bootmode_t enum above
  uint8_t playstart; // r from v206 mk2
  uint8_t playend;   // g
  uint8_t playcount; // b
  uint8_t bootloaderlock; // is programmatic triggering of bootloader allowed
  uint8_t  serverdown_playstart;
  uint8_t  serverdown_playend;
  uint8_t  serverdown_unused1;
  uint32_t serverdown_millis;
} user_params_t;

// array of LED data (sent to LEDs)
rgb_t leds[nLEDs];

// global which is active LED
uint8_t ledn;

// number of entries a color pattern can contain
#define PATT_MAX 32

// define what is in the user data section
//typedef struct __attribute((packed)) {
typedef struct {
  user_params_t startup_params;
  patternline_t pattern[PATT_MAX];
} userdata_t;

/*
 * "Notes" are user-writable and -readable blobs of data
 * report2 size is 60 bytes (must be mult of 4, must be <64 for feature report)
 * byte 0 reportid
 * byte 1 cmd
 * byte 3 noteid
 * byte 4-59 notedata == 55 bytes
 *
 * Note size = 50
 * Note count = 20
 * Total size = 1000 < FLASH_PAGE_SIZE = 1024
 * .userNotesFlashSection is in flash at address 0xf800 (64k - (2*1k))
 */
#define NOTE_SIZE 50
#define NOTE_COUNT 20

// define what is in a user note
typedef struct {
  char note[NOTE_SIZE];  // just a string for now
} usernote_t;

// just an idea, make the entire notes block its own struct
//typedef struct {
//  usernote_t notes[NOTE_COUNT]
//} usernotes_t;

/*
 * Flash / non-volatile user data & user color pattern
 *
 * 6 bytes / patternline (fade is 2bytes)
 * => 1024 bytes / 6 = 170 pattern lines potentially (or 10 16-line patterns =960 bytes)
 *
 * FLASH_PAGE_SIZE = 1024 (Gecko_SDK/platform/Device/SiliconLabs/EFM32HG/Include/efm32hg309f64.h)
 * FLASH_SIZE = 65536 (64k)
 * .userFlashSection is in flash at address 0xfc00 (64k - (1*1k))
 */
//uint32_t *patterFlashAddress = (uint32_t *)(FLASH_SIZE - (2*FLASH_PAGE_SIZE));

// Flash copy of user startup params and LED patterns
// can at most be FLASH_PAGE_SIZE big (1024 bytes)
__attribute__ ((section(".userFlashSection")))
const userdata_t userFlash = {
  .startup_params =
  {
    .bootmode = BOOT_NORMAL,
    .playstart = 0,
    .playend = PATT_MAX,  // one more than
    .playcount = 0,
    .bootloaderlock = 0,
    .serverdown_playstart = 0,
    .serverdown_playend = 0,
    .serverdown_millis = 0,
  },
  .pattern =
  {
    //    R     G     B    fade ledn
    { { 0xff, 0x00, 0x00 },  50, 1 }, // 0  red A
    { { 0xff, 0x00, 0x00 },  50, 2 }, // 1  red B
    { { 0x00, 0x00, 0x00 },  50, 0 }, // 2  off both
    { { 0x00, 0xff, 0x00 },  50, 1 }, // 3  grn A
    { { 0x00, 0xff, 0x00 },  50, 2 }, // 4  grn B
    { { 0x00, 0x00, 0x00 },  50, 0 }, // 5  off both
    { { 0x00, 0x00, 0xff },  50, 1 }, // 6  blu A
    { { 0x00, 0x00, 0xff },  50, 2 }, // 7  blu B
    { { 0x00, 0x00, 0x00 },  50, 0 }, // 8  off both
    { { 0x80, 0x80, 0x80 }, 100, 0 }, // 9  half-bright, both LEDs
    { { 0x00, 0x00, 0x00 }, 100, 0 }, // 10 off both
    { { 0xff, 0xff, 0xff },  50, 1 }, // 11 white A
    { { 0x00, 0x00, 0x00 },  50, 1 }, // 12 off A
    { { 0xff, 0xff, 0xff },  50, 2 }, // 13 white B
    { { 0x00, 0x00, 0x00 }, 100, 2 }, // 14 off B
    { { 0x00, 0x00, 0x00 }, 100, 0 }, // 15 off everyone
  },
};

// Flash copy of userNotes
// can at most be FLASH_PAGE_SIZE big (1024 bytes)
__attribute__ ((section(".userNotesFlashSection")))
const usernote_t userNotesFlash[NOTE_COUNT] = {
  {"Note0: This is a test note"},
  {"Note1: Here is another test note"},
  {"Note2: This is a max size note. Note is 50 bytes.!"},
  {"Note3:67890123456789012345678901234567890123456789"},
  //01234567890123456789012345678901234567890123456789
  //          1         2         3         4
};

// RAM copy of non-volatile notes
// must be word-aligned because that's what MSC_WriteWord() needs
SL_ALIGN(4)
usernote_t userNotes[NOTE_COUNT] SL_ATTRIBUTE_ALIGN(4);

// RAM copy of non-volatile startup params & color pattern
// must be word-aligned because that's what MSC_WriteWord() needs
SL_ALIGN(4)
userdata_t userData SL_ATTRIBUTE_ALIGN(4);

uint8_t playpos   = 0; // current play position
//
uint8_t playstart = 0; // start play position
uint8_t playend   = PATT_MAX; // end play position
uint8_t playcount = 0; // number of times to play loop, or 0=infinite
//#define playstart userData.startup_params.playstart
//#define playend   userData.startup_params.playend
//#define playcount userData.startup_params.playcount

// play modes, valid values for "playing"
enum {
    PLAY_OFF       = 0,  // off
    PLAY_ON        = 1,  // normal playing pattern
    PLAY_POWERUP   = 2,  // playing from a powerup
    PLAY_DIRECTLED = 3   // direct LED addressing (FIXME: this is dumb)
};

uint8_t playing = PLAY_OFF; // playing values: as above enum

bool doPatternWrite = false;

patternline_t ptmp;  // temp pattern holder
rgb_t ctmp;      // temp color holder
uint16_t ttmp;   // temp time holder
uint8_t ledn;    // temp ledn holder

// The uptime in milliseconds, maintained by the SysTick timer.
volatile uint32_t uptime_millis=0;

// next time led_update should run
const uint32_t led_update_millis = 10;  // tick msec
uint32_t led_update_next;

uint32_t pattern_update_next;

uint16_t serverdown_millis = 0;
uint32_t serverdown_update_next;
uint8_t  serverdown_playstart = 0;        // start play position for serverdown
uint8_t  serverdown_playend   = PATT_MAX; // end play position for serverdown

uint32_t last_misc_millis;

// Set by 'G' "gobootload" command
bool shouldRebootToBootloader = false;
// Set when a Note write should be issued
bool doNotesWrite = false;
// Set when USB is properly setup by host PC
bool usbHasBeenSetup = false;

// valid values for `startupState` (this was `doStartup` bool)
enum {
   STARTUP_BOOT  = 0,
   STARTUP_CHECK = 1,
   STARTUP_DONE  = 2,
};
// should powerup logic be done (must wait until chip & usb stabilize)
uint8_t startupState = STARTUP_BOOT;  // 0 = still booting, 1 = doing startup, 2 = startup done

// For sending back HID Descriptor in setupCmd
static void  *hidDescriptor = NULL;

// The USB report packet received from the host
// could be REPORT_COUNT or REPORT2_COUNT long
// first byte is reportId
SL_ALIGN(4)
static uint8_t  inbuf[REPORT2_COUNT] SL_ATTRIBUTE_ALIGN(4);

// The USB report packet to send to the host
// generally it's a copy of the last report received, then modified
SL_ALIGN(4)
static uint8_t reportToSend[REPORT2_COUNT] SL_ATTRIBUTE_ALIGN(4);

// forward declaration for callbacks struct
int setupCmd(const USB_Setup_TypeDef *setup);
void stateChange(USBD_State_TypeDef oldState, USBD_State_TypeDef newState);

/* Define callbacks that are called by the USB stack on different events. */
static const USBD_Callbacks_TypeDef callbacks =
{
  .usbReset       = NULL,         // Called whenever USB reset signalling is detected
  .usbStateChange = stateChange,  // Called whenever the device change state.
  .setupCmd       = setupCmd,     // Called on each setup request received from host.
  .isSelfPowered  = NULL,         // Called when the device stack needs to query if the device is currently self- or bus-powered.
  .sofInt         = NULL          // Called at each SOF interrupt. If NULL, device stack will not enable the SOF interrupt.
};

/* Fill the init struct. This struct is passed to USBD_Init() in order
 * to initialize the USB Stack */
static const USBD_Init_TypeDef initstruct =
{
  .deviceDescriptor    = &deviceDesc,
  .configDescriptor    = configDesc,
  .stringDescriptors   = strings,
  .numberOfStrings     = sizeof(strings)/sizeof(void*),
  .callbacks           = &callbacks,
  .bufferingMultiplier = bufferingMultiplier,
  .reserved            = 0
};


/* This functions is injected into the Interrupt Vector Table, and will be
 * called whenever the SysTick timer fires (whose interval is configured inside
 * main() further below).
 * It provides the equivalent of "millis()" in the variable "uptime_millis",
 * but it does roll-over
 * It must be called "SysTick_Handler"
 */
void SysTick_Handler() {
  uptime_millis++;
}
// ease-of-use function because I'm used to Arduino
#define millis() (uptime_millis)
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
int main()
{
  // Runs the Silicon Labs chip initialisation stuff, that also deals with
  // errata (implements workarounds, etc).
  CHIP_Init();

  // Disable the watchdog that the bootloader started.
  WDOG->CTRL = 0;

  //CMU_ClockEnable(cmuClock_DMA, true);
  // USART is a HFPERCLK peripheral. Enable HFPERCLK domain and USART0.
  CMU_ClockEnable(cmuClock_HFPER, true);
  CMU_ClockEnable(cmuClock_USART0, true);
  // Switch on the clock for GPIO. Even though there's no immediately obvious
  // timing stuff going on beyond the SysTick below, it still needs to be
  // enabled for the GPIO to work.
  CMU_ClockEnable(cmuClock_GPIO, true);

  // Fix the fact that Tomu bootloader doesn't reset pin state
  GPIO_PinModeSet(gpioPortA, 0, gpioModeDisabled, 0);
  GPIO_PinModeSet(gpioPortB, 7, gpioModeDisabled, 0);

  // Enable the capacitive touch sensor. Remember, this consumes TIMER0 and
  // TIMER1, so those are off-limits to us.
  // CAPSENSE_Init();

  // Sets up and enable the `SysTick_Handler' interrupt to fire once every 1ms.
  // ref: http://community.silabs.com/t5/Official-Blog-of-Silicon-Labs/Chapter-5-MCU-Clocking-Part-2-The-SysTick-Interrupt/ba-p/145297
  if (SysTick_Config(CMU_ClockFreqGet(cmuClock_CORE) / 1000)) {
    // Something went wrong.
    while (1);
  }

  SpinDelay(100); // wait 100ms to let power stabilize

  dbg_setup();  // sets up LEUART if DEBUG is set

  dbg_str("\nblink1mk3-firmware-v30x startup...\n");
  dbg_printf("toboot_runtime: count:%d model:%x\n",
             toboot_runtime.boot_count, toboot_runtime.board_model);

  toboot_runtime.boot_count = 0; // reset boot count to say we're alive
  // FIXME: how is the toboot_runtime RAM being preserved on power cycle?

  ws2812_setupSpi();

#if 0
  dbg_printf("refFreq:%ld\n", CMU_ClockFreqGet(cmuClock_HFPER));  // 21000000
  dbg_printf("CTRL   :%lx\n", USART0->CTRL);    // 1025 = 0x0401
  dbg_printf("FRAME  :%lx\n", USART0->FRAME);   // 4105 = 0x1009
  dbg_printf("CMD    :%lx\n", USART0->CMD);     // 0
  dbg_printf("STATUS :%lx\n", USART0->STATUS);  // 71   = 0x0047
  dbg_printf("CLKDIV :%lx\n", USART0->CLKDIV);  // 768  = 0x300
  dbg_printf("ROUTE  :%lx\n", USART0->ROUTE);   // 0x0402
  dbg_printf("CMU_CTRL         : %lx\n", CMU->CTRL );         // 0xc262c 796204 ?
  dbg_printf("CMU_HFCORECLKDIV : %lx\n", CMU->HFCORECLKDIV ); // 0
  dbg_printf("CMU_HFPERCLKDIV  : %lx\n", CMU->HFPERCLKDIV );  // 0x0100
  dbg_printf("CMU_HFCORECLKEN0 : %lx\n", CMU->HFCORECLKEN0 ); // 0x0004
  dbg_printf("CMU_HFPERCLKEN0  : %lx\n", CMU->HFPERCLKEN0 );  // 0x016b
#endif

  userDataLoad();

  #if DEBUG_STARTUP
  dbg_printf("before startup params. size:%d bootmode:%d\n", sizeof(userdata_t), userData.startup_params.bootmode );
  #endif

  SpinDelay(100); // wait for flash copy to complete

  // load up variables
  //if( userData.startup_params.bootmode == BOOT_PLAY ) {
  dbg_str("loading startup params\n");
  playstart = userData.startup_params.playstart;
  playend   = userData.startup_params.playend;
  playcount = userData.startup_params.playcount;
  // serverdown variables
#if 0
  serverdown_playstart = userData.startup_params.serverdown_playstart;
  serverdown_playend   = userData.startup_params.serverdown_playend;
  serverdown_millis    = userData.startup_params.serverdown_millis;
  if( serverdown_millis ) {
    serverdown_update_next = 500 + millis() + serverdown_millis; // FIXME: 500 because that's our startup delay
  }
#endif
  //}

  // set initial play state
  //  if(        userData.startup_params.bootmode == BOOT_OFF ) {
  //  playing = PLAY_OFF;
  //} else if( userData.startup_params.bootmode == BOOT_NORMAL ) {
  //  playing = PLAY_OFF;
  //} else if( userData.startup_params.bootmode == BOOT_PLAY ) {
  //  playing = PLAY_ON;
  //}


  #if DEBUG_STARTUP
  #if 0  // debug: dump out loaded pattern
  for( int i=0; i<8; i++) { // should be PATT_MAX
    ctmp = userData.pattern[i].color;
    ttmp = userData.pattern[i].dmillis;
    ledn = userData.pattern[i].ledn;
    dbg_printf("patt[%d] rgb:%2x%2x%2x t:%d l:%d\n",
               i, ctmp.r, ctmp.g, ctmp.b, ttmp, ledn);
  }
  #endif
  // debug: dump out state variables
  dbg_printf("variable:      playstart/end/cnt: %d/%d/%d\n",
             playstart, playend, playcount);
  dbg_printf("userdata: bm:%d playstart/end/cnt: %d/%d/%d\n",
             userData.startup_params.bootmode, userData.startup_params.playstart,
             userData.startup_params.playend, userData.startup_params.playcount);
  dbg_printf("serverdown_playstart/playend/millis: %d/%d/%d\n",
             serverdown_playstart, serverdown_playend, serverdown_millis);
  #endif


  notesLoadAll();

  makeSerialNumber();  // Make USB serial number from chip unique Id

  hidDescriptor = (void*) USBDESC_HidDescriptor; // FIXME

  // standard blink1 startup white fadeout
  for( uint8_t i=255; i>0; i-- ) {
    SpinDelay(1);
    uint8_t j = i>>4;      // not so bright, please
    setLED(j,j,j, 0); // LED A
    setLED(j,j,j, 1); // LED B
    displayLEDs();
  }

  // Enable the USB controller.
  // Remember, this consumes TIMER2 as per -DUSB_TIMER=USB_TIMER2 in Makefile
  // because TIMER0 & TIMER1 are already taken by the capacitive touch sensors.
  //
  int rc = USBD_Init(&initstruct);
  UNUSED(rc);
  dbg_printf("usbd_init rc:%d\n", rc);

#if 0
  // When using a debugger it is practical to uncomment the following three
  // lines to force host to re-enumerate the device.
  USBD_Disconnect();
  USBTIMER_DelayMs(1000);
  USBD_Connect();
#endif


  off();
  displayLEDs(); // why this here, to prime the system?

  // main loop
  while(1) {

    updateLEDs();
    updateMisc();

  }

}

/**********************************************************************
 * handleMessage(char* inbuf) -- main command router
 *
 * inbuf[] is 8 bytes long (or 64 bytes for report2)
 *  byte0 = report-id
 *  byte1 = command
 *  byte2..byte7 = args for command
 *
 * Available commands:
 *  - Fade to RGB color       format: { 1, 'c', r,g,b,     th,tl, n }
 *  - Set RGB color now       format: { 1, 'n', r,g,b,       0,0, n } (*)
 *  - Read current RGB color  format: { 1, 'r', n,0,0,       0,0, n } (2)
 *  - Serverdown tickle/off   format: { 1, 'D', on,th,tl,  st,sp,ep } (*)
 *  - PlayLoop                format: { 1, 'p', on,sp,ep,c,    0, 0 } (2)
 *  - Playstate readback      format: { 1, 'S', 0,0,0,       0,0, 0 } (2)
 *  - Set color pattern line  format: { 1, 'P', r,g,b,     th,tl, p }
 *  - Save color patterns     format: { 1, 'W', 0,0,0,       0,0, 0 } (2)
 *  - read color pattern line format: { 1, 'R', 0,0,0,       0,0, p }
 *  - Set ledn                format: { 1, 'l', n,0,0,       0,0, 0 } (2+)
 *  - Read EEPROM location    format: { 1, 'e', ad,0,0,      0,0, 0 } (1)
 *  - Write EEPROM location   format: { 1, 'E', ad,v,0,      0,0, 0 } (1)
 *  - Get version             format: { 1, 'v', 0,0,0,       0,0, 0 }
 *  - Test command            format: { 1, '!', 0,0,0,       0,0, 0 }
 *  - Write 50-byte note      format: { 2, 'F', noteid, data0 ... data99 } (3)
 *  - Read  50-byte note      format: { 2, 'f', noteid, data0 ... data99 } (3)
 *  - Go to bootloader        format: { 1, 'G', 'o','B','o','o','t',0 } (3)
 *  - Lock go to bootload     format: { 2','L'  'o','c','k','B','o','o','t','l','o','a','d'} (3)
 *  - Set startup params      format: { 1, 'B', bootmode, playstart,playend,playcnt,0,0} (3)
 *  - Get startup params      format: { 1, 'b', 0,0,0, 0,0,0        } (3)
 *  - Server mode tickle      format: { 1, 'D', {1/0},th,tl, {1,0},sp, ep }
 *  - Get chip unique id      format: { 2, 'U', 0 } (3)
 *
 * x Fade to RGB color        format: { 1, 'c', r,g,b,      th,tl, ledn }
 * x Set RGB color now        format: { 1, 'n', r,g,b,        0,0, ledn }
 * x Play/Pause, with pos     format: { 1, 'p', {1/0},pos,0,  0,0,    0 }
 * x Play/Pause, with pos     format: { 1, 'p', {1/0},pos,endpos, 0,0,0 }
 * x Write color pattern line format: { 1, 'P', r,g,b,      th,tl,  pos }
 * x Read color pattern line  format: { 1, 'R', 0,0,0,        0,0, pos }
 *
 *********************************************************************/
static void handleMessage(uint8_t reportId)
{
#if DEBUG_HANDLEMESSAGE
  dbg_printf("%d:%x,%x,%x,%x,%x,%x,%x,%x\n", reportId,
          inbuf[0],inbuf[1],inbuf[2],inbuf[3],inbuf[4],inbuf[5],inbuf[6],inbuf[7] );
#endif

  // pre-load response with request, contains report id
  uint8_t count = (reportId==REPORT_ID) ? REPORT_COUNT : REPORT2_COUNT;
  memcpy( (void*)reportToSend, (void*)inbuf, count);

  uint8_t rId;
  uint8_t cmd;
  rgb_t c; // we need this for many commands so pre-parse it
  rId = inbuf[0];
  cmd = inbuf[1];
  c.r = inbuf[2];
  c.g = inbuf[3];
  c.b = inbuf[4];
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

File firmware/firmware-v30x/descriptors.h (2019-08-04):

/***************************************************************************//**
 * @file descriptors.h
 * @brief USB descriptors
 * @author Energy Micro AS
 * @version 1.01
 *******************************************************************************
 * @section License
 * <b>(C) Copyright 2012 Energy Micro AS, http://www.energymicro.com</b>
 *******************************************************************************
 *
 * Permission is granted to anyone to use this software for any purpose,
 * including commercial applications, and to alter it and redistribute it
 * freely, subject to the following restrictions:
 *
 * 1. The origin of this software must not be misrepresented; you must not
 *    claim that you wrote the original software.
 * 2. Altered source versions must be plainly marked as such, and must not be
 *    misrepresented as being the original software.
 * 3. This notice may not be removed or altered from any source distribution.
 * 4. The source and compiled code may only be used on Energy Micro "EFM32"
 *    microcontrollers and "EFR4" radios.
 *
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
 * Energy Micro AS will not be liable for any consequential, incidental, or
 * special damages, or any other relief, or for any claim by any third party,
 * arising from your use of this Software.
 *
 *****************************************************************************/
#ifdef __cplusplus
extern "C" {
#endif

#define VENDOR_ID     0x27B8 // real one
#define PRODUCT_ID    0x01ED // real one
//#define VENDOR_ID     0x27B8
//#define PRODUCT_ID    0x01Ef
#define DEVICE_VER		0x0101	/* Program version */

#define REPORT_ID  1
#define REPORT2_ID  2
#define REPORT_COUNT 8
#define REPORT2_COUNT 60   // 60 = 15*4, must be 4-byte multiple in length & 4-byte aligned


SL_ALIGN(4)
const char MyHIDReportDescriptor[] SL_ATTRIBUTE_ALIGN(4) =
{
    0x06, 0xAB, 0xFF,
    0x0A, 0x00, 0x20,
    
    0xA1, 0x01,                    // COLLECTION (Application)
    0x15, 0x00,                    //   LOGICAL_MINIMUM (0)
    0x26, 0xff, 0x00,              //   LOGICAL_MAXIMUM (255)
    0x75, 0x08,                    //   REPORT_SIZE (8)
    0x85, REPORT_ID,               //   REPORT_ID (1)
    0x95, REPORT_COUNT,            //   REPORT_COUNT (8)
    0x09, 0x00,                    //   USAGE (Undefined)
    0xb2, 0x02, 0x01,              //   FEATURE (Data,Var,Abs,Buf)
    0x75, 0x08,                    //   REPORT_SIZE (8)
    0x85, REPORT2_ID,               //   REPORT_ID (1)
    0x95, REPORT2_COUNT,            //   REPORT_COUNT (8)
    0x09, 0x00,                    //   USAGE (Undefined)
    0xb2, 0x02, 0x01,              //   FEATURE (Data,Var,Abs,Buf)
    0xc0,                          // END_COLLECTION
};

/* 
// old blink1 hid descriptor
SL_ALIGN(4)
const char MyHIDReportDescriptor[] SL_ATTRIBUTE_ALIGN(4) =
{
    0x06, 0xAB, 0xFF,
    0x0A, 0x00, 0x20,
    
    //0x06, 0x00, 0xff,              // USAGE_PAGE (Generic Desktop)
    //0x09, 0x01,                    // USAGE (Vendor Usage 1)
    
    0xA1, 0x01,                    // COLLECTION (Application)
    0x15, 0x00,                    //   LOGICAL_MINIMUM (0)
    0x26, 0xff, 0x00,              //   LOGICAL_MAXIMUM (255)
    0x75, 0x08,                    //   REPORT_SIZE (8)
    0x85, REPORT_ID,               //   REPORT_ID (1)
    0x95, REPORT_COUNT,            //   REPORT_COUNT (8)
    0x09, 0x00,                    //   USAGE (Undefined)
    0xb2, 0x02, 0x01,              //   FEATURE (Data,Var,Abs,Buf)
    0xc0,                          // END_COLLECTION
};
*/

/*
SL_ALIGN(4)
const char MyHIDReportDescriptor[] SL_ATTRIBUTE_ALIGN(4) =
{
  0x06, 0xAB, 0xff,              // USAGE_PAGE (Generic Desktop)
  0x09, 0x01,                    // USAGE (Vendor Usage 1)
  
  0xA1, 0x01,                    // COLLECTION (Application)
  0x85, REPORT_ID,               //     REPORT_ID (1)
  0x09, 0x00,                    //     USAGE (Undefined)
  0x15, 0x00,                    //     LOGICAL_MINIMUM (0)
  0x26, 0xff, 0x00,              //     LOGICAL_MAXIMUM (255)
  0x75, 0x08,                    //     REPORT_SIZE (8)
  0x95, REPORT_COUNT,            //     REPORT_COUNT (8)
  
  0x85, REPORT2_ID,              //     REPORT_ID (2)
  0x09, 0x00,                    //     USAGE (Undefined)
  0x95, REPORT2_COUNT,           //     REPORT_COUNT (64)
  0x75, 0x08,                    //     REPORT_SIZE (8)

  0xc0,                          // END_COLLECTION

};
*/
 /*
SL_ALIGN(4)
const char MyHIDReportDescriptor[] SL_ATTRIBUTE_ALIGN(4) =
{

  //0x06, 0x00, 0xff,              // USAGE_PAGE (Generic Desktop)
  //0x09, 0x01,                    // USAGE (Vendor Usage 1)

  0x06, 0xAB, 0xff,              // USAGE_PAGE (Generic Desktop)
  0x09, 0x01,                    // USAGE (Vendor Usage 1)
  
  0xA1, 0x01,                    // COLLECTION (Application)
  0xA1, 0x02,                    //   Collection (Logical)
  0x85, REPORT_ID,               //     REPORT_ID (1)
  0x15, 0x00,                    //     LOGICAL_MINIMUM (0)
  0x26, 0xff, 0x00,              //     LOGICAL_MAXIMUM (255)
  0x95, REPORT_COUNT,            //     REPORT_COUNT (8)
  0x75, 0x08,                    //     REPORT_SIZE (8)
  0x09, 0x00,                    //     USAGE (Undefined)
  0xb2, 0x02, 0x01,              //     FEATURE (Data,Var,Abs,Buf)
  0xc0,                          //   END_COLLECTION
    
  0xA1, 0x02,                    //   Collection (Logical)
  0x85, REPORT2_ID,              //     REPORT_ID (2)
  0x15, 0x00,                    //     LOGICAL_MINIMUM (0)
  0x26, 0xff, 0x00,              //     LOGICAL_MAXIMUM (255)
  0x95, REPORT2_COUNT,           //     REPORT_COUNT (64)
  0x75, 0x08,                    //     REPORT_SIZE (8)
  0x09, 0x01,                    //     USAGE (Undefined)
  0xb2, 0x02, 0x01,              //     FEATURE (Data,Var,Abs,Buf)
  0xc0,                          //   END_COLLECTION
  0xc0,                          // END_COLLECTION
};
 */
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

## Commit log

2018-03-20 moving schematic over from blink1/hardware/schematic
    [blink1mk3_001.brd, blink1mk3_001.sch]
2018-03-20 actually route all the lines
    [blink1mk3_001.brd]
2018-03-20 fix DI pin so it does not badly interact with tomu firmware
    [blink1mk3_001.brd, blink1mk3_001.sch]
2018-03-21 moved decoupling caps because of bottomside front support
    [blink1mk3_001.brd]
2018-03-21 better pcb layout
    [blink1mk3_001.brd, blink1mk3_001.sch]
2018-03-21 version submitted to oshpark
    [blink1mk3_001.brd, blink1mk3_001.sch]
2018-03-22 added blink1mk3_002 schematic
    [blink1mk3_002.brd, blink1mk3_002.sch]
2018-04-02 fixes for toboot and actual efm32HG309F64 board
    [leuart.h, main.c]
2018-04-02 refactor a bit, basic blink1 functionality on efm32hg309f64 / tomu
    [blink1mk3_002.brd]
2018-04-03 added compile-time switch for handleMessage() debug since it can crash the chip
    [main.c]
2018-04-06 added BOARD_TYPE_... defines to move between blink1mk3, tomu, efm32hgdevkit
    [blink1mk3_002.brd]
2018-04-08 reboot to bootloader works
    [main.c]
2018-04-09 oops fixed bootloader build
    [toboot-main-blink1.c]
2018-04-09 first cut at booster building
2018-04-10 firmware: fixed toboot bootloader setup, I think
    [descriptors.h, main.c]
2018-04-10 bootloader: add BOARD_TYPE_BLINK1 sections, mostly to be filled in later
2018-04-10 pattern saving to flash working correctly now, but had to modify linker script to do it cleanly
    [main.c]
2018-04-10 bootloader: added proper GPIO reset for BOARD_TYPE_BLINK1
    [toboot-main-blink1.c]
2018-04-12 fix comment about AUTORUN and comment out boot_failures return for now
    [toboot-main-blink1.c]
2018-04-12 clean up test3 firmware, mostly about flash writing. patternw writing works fine but why does notes writing crash the chip?
    [main.c]
2018-04-24 blink1 micro: added registration holes, cleanup
    [blink1mk3_micro1.brd, blink1mk3_micro1.sch]
2018-05-08 added business card variant, and 3535 LED variant
    [blink1mk3_002_3535.brd, blink1mk3_002_3535.sch, blink1mk3_card.brd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]
2018-05-08 card layout update
    [blink1mk3_card.brd]
2018-05-09 sync schematic experiments
    [blink1mk3_003.brd, blink1mk3_003.sch, blink1mk3_004.brd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]
2018-05-09 update pcbs with correct filename labels
    [blink1mk3_004.brd, blink1mk3_005t.brd, blink1mk3_micro1a.brd]
2018-05-16 added business card idea
    [blink1mk3_card1.brd, blink1mk3_card1.sch]
2018-05-18 add more micro ideas
    [blink1mk3_micro1a.brd, blink1mk3_micro1b.brd, blink1mk3_micro1b.sch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]
2018-05-22 "make dfu" allows blink1-tool to fail (in the case of first programming)
2018-05-22 add note about doing "power on" when using Jlink to do bootloader program
2018-05-22 fix EFM32HG309 pad spacing issue. omg what a slog
    [blink1mk3_004.brd, blink1mk3_004.sch, blink1mk3_005t.brd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]
2018-05-24 fix QFN footprint again, add blink1mk3_card2
    [blink1mk3_005t.brd, blink1mk3_005t.sch, blink1mk3_card1.brd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]
2018-05-24 small blink1mk3_card2 pcb fixes
    [blink1mk3_card2.brd, blink1mk3_card2.sch]
2018-05-24 added blink1mk3-test4 firmware, fixes first two pattern lines getting nuked problem, adds startup_params datastruct (but no action on it yet)
    [descriptors.h, leuart.h, main.c]
2018-05-25 finally got usernotes working correctly on both Windows and Mac (due to my not understanding report size limitations)
    [descriptors.h, main.c]
2018-05-26 fixed usernotes flash saving problem (buffer must be word-aligned: SL_ALIGN(4)
    [main.c]
2018-06-11 bootlaoder: trying to fix SWD + SWC pin short to start bootloader
    [toboot-main-blink1.c]
2018-06-11 added random boot mode, trying out capsense, currently causes lockups
2018-07-13 fix up BOARD_ defines
    [main.c, ws2812_spi.h]
2018-08-03 added blink1mk3-test5
    [blink1mk3_micro1c.brd]
2018-08-11 schematic directory cleanup
    [blink1mk3_card.brd, blink1mk3_card.sch, blink1mk3_card1-test.brd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]
2018-09-11 bootloader: small reminder about power on when testing
2018-09-11 schematics: added blink1mk3-005t3
    [blink1mk3-usbctest1.brd, blink1mk3-usbctest1.sch, blink1mk3_005t3.brd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]
2018-09-11 schematic: added blink1mk3_micrco1d2
    [blink1mk3_micro1d2.brd, blink1mk3_micro1d2.sch]
2018-10-09 added blink1mk3_005t4 pcb
    [blink1mk3_005t4.brd, blink1mk3_005t4.sch]
2018-11-15 small blink1 mk3 schematic fixes before release to manufacturing
    [blink1mk3_005t4.brd, blink1mk3_005t4.sch]
2018-11-15 added programming jig experiments
    [blink1micro-programming-jig.brd, blink1micro-programming-jig.sch, blink1micro-programming-jig2.brd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]
2018-11-28 bootloader: update bootloader to track new toboot
2018-11-28 pcb: enlarged silkscreen text for seeed
    [blink1mk3_005t5.brd, blink1mk3_005t5.sch]
2018-11-29 bootloader: set webusb landing page to dfu.blink1.thingm.com
2018-11-30 firmware: add SWD pins connect checking to reboot to bootloader
    [main.c]
2018-11-30 add openocd-stlinkv2, cheap 8 buck SWD programmer!
2018-12-02 firmware: cleaned up hardware SWD pin bootload triggering, small comments added
2018-12-02 bootloader: first cut at ws2812 support
2018-12-14 firmware: debugging startup logic, having issues with copying userData to variables. argh
    [main.c]
2018-12-15 firmware: clarify logic on usb power up, turn off debug, bump version to prod
2018-12-16 rework startup logic, fix serial number, still researching weird hub-related startup issue
    [main.c]
2018-12-19 fixed dir name typo
    [descriptors.h, leuart.h, main.c]
2019-01-15 schematic mk3_005t5, fix D1 part number
    [blink1mk3_005t5.brd, blink1mk3_005t5.sch]
2019-04-17 updated README a little
    [blink1mk3_005t5.brd, blink1mk3_005t5.sch]
2019-07-10 added new mk3 board variations
    [blink1mk3_005t5_5050.brd, blink1mk3_005t5_5050.sch, blink1mk3_005t5_5050_4l.brd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]
2019-08-04 Advertise as self-powered (but still needing bus power) instead of bus-powered as work-around to USB suspend causing USB stack to pause chip
2019-08-30 usbc tests
    [blink1mk3_005t6_5050_4l_usbc.brd, blink1mk3_005t6_5050_4l_usbc.sch, usbc-plug-test.brd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]
2019-09-17 rename sch 005t6_5050_4l to 005t6_4L
    [blink1mk3_005t6_4L.brd, blink1mk3_005t6_4L.sch, blink1mk3_005t6_5050_4l_usbc.brd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]
2020-03-10 more usbc work
    [blink1mk3_005t6_3535_4l_usbc.brd, blink1mk3_005t6_3535_4l_usbc.sch]
2020-03-10 save micro 4l for posterity
    [blink1mk3_micro1e_4l.brd, blink1mk3_micro1e_4l.sch]
2020-03-10 added uncomplete work on 5050-based usbc
    [blink1mk3_005t6_5050_4l_usbc2020.brd, blink1mk3_005t6_5050_4l_usbc2020.sch]
2020-03-10 schem reorg
    [blink1_trinket0.brd, blink1_trinket0.sch, blink1mk3-prog-jig2.brd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]
2021-02-13 added 3535 usbc variant
    [blink1mk3_usbc3535A.brd, blink1mk3_usbc3535A.sch]
2021-02-16 update usbc3535A board
    [blink1mk3_usbc3535A.brd]
2021-05-08 attempt to address startup params issue #8
    [main.c]
2021-05-09 attempt to fix startup user params not being copied to main running vars. This is second problem in issue #8
    [main.c]

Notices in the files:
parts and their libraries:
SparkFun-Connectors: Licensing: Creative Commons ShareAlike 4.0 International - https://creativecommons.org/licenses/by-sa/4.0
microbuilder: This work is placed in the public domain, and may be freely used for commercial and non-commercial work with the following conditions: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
